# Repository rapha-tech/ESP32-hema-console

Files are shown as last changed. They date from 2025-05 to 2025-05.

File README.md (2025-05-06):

# ESP32 hema console
 New PCB for the small console from hema to use an ESP32

## <https://github.com/ducalex/retro-go>
The esp32 uses Retro-go to emulate games

## Side by side comparison with the original one
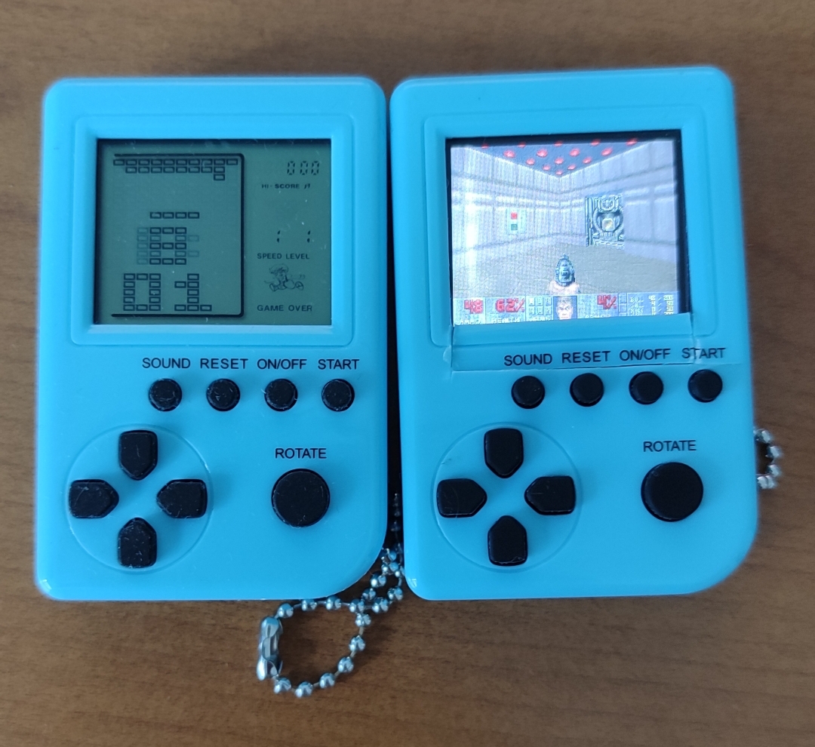
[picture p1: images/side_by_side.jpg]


## Some pictures of the PCB
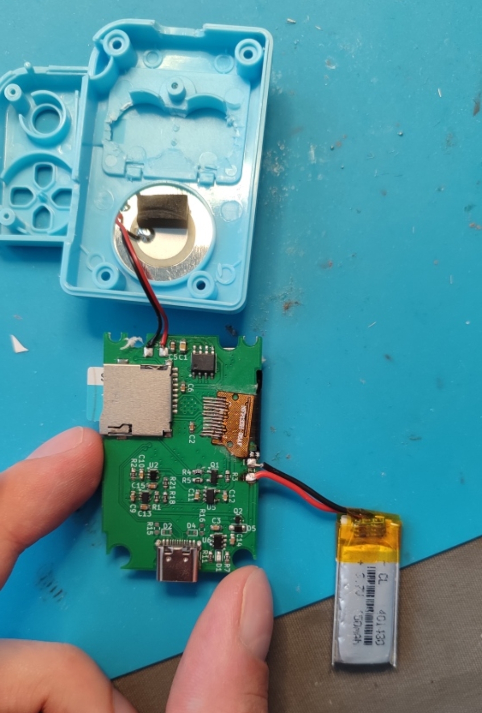
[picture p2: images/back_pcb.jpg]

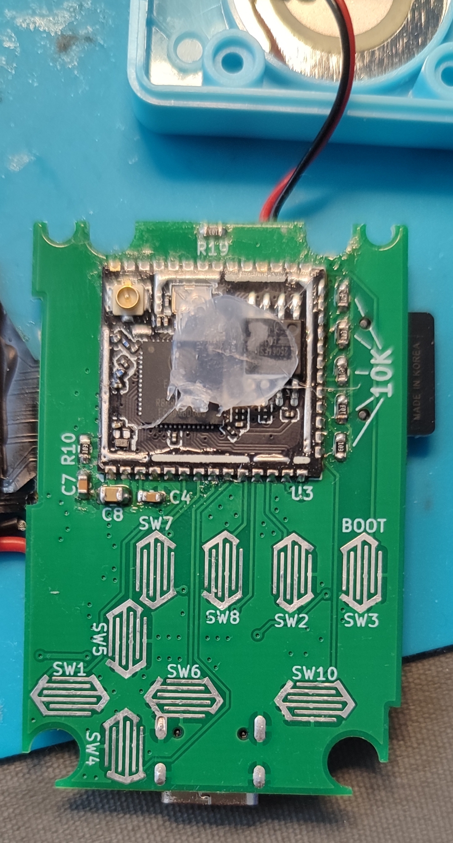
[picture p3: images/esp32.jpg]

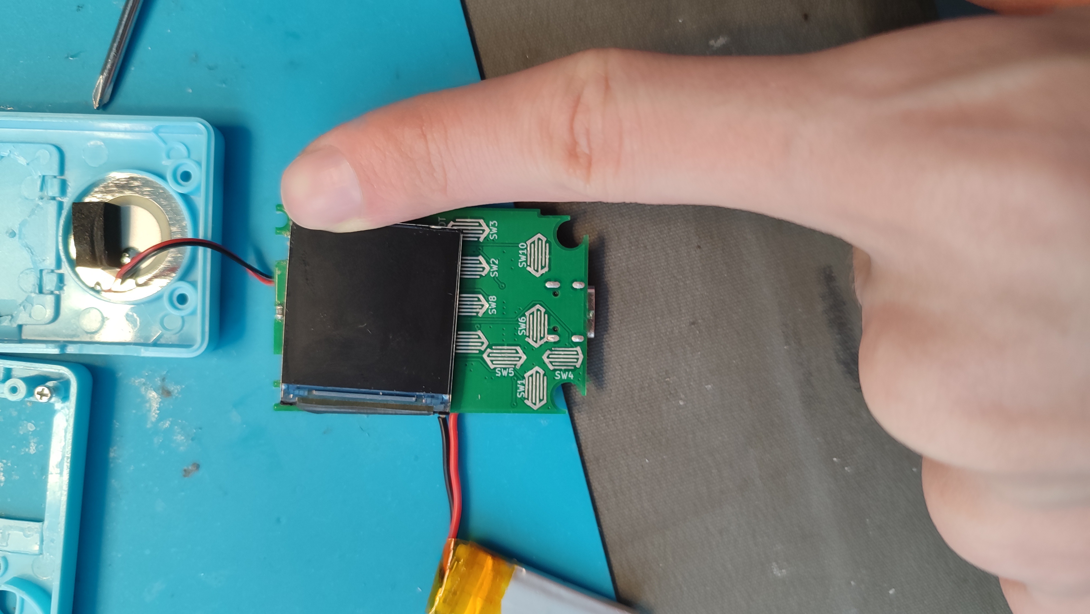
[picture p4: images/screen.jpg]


Known problems :
- The buttons doesn't make great contact compared to the original PCB

Components :
- ESP32 module without PCB antenna
- 1.54 inches IPS 240*240px
- about 3*30*30mm battery or 4*15*30mm

Note : it is almost the same schematic as my Retro-Ruler
## <https://github.com/rapha-tech/Retro-Ruler>

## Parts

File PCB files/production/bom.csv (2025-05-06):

Designator | Footprint | Quantity | Value | LCSC Part #
B1 | BAT | 1 | battery_3.7v
C1, C8 | 0805 | 2 | 10uF
C10, C11, C12, C4, C9 | 0603 | 5 | 1uF
C13, C15, C2, C5, C6, C7 | 0603 | 6 | 100nF
C14, C3 | 0603 | 2 | 2.2uF
D1 | 0603 | 1 | RLED
D2, D4 | D_SOD-523 | 2 | LESD5D5.0CT1G
D5 | D_SOD-323_HandSoldering | 1 | BAT760
DS1 | ST7789-320x240 | 1 | ST7789
J1 | USB_C_Receptacle_GCT_USB4105-xx-A_16P_TopMnt_Horizontal | 1 | USB_C_Receptacle_USB2.0_14P
J2 | micro_sd | 1 | Micro_SD_Card
Q1 | SOT-23 | 1 | NPN_S9013
Q2 | SOT-723 | 1 | CJ3139K
R1, R10, R13, R14, R18, R19, R2, R21, R5, R6, R8, R9 | 0603 | 12 | 10K
R11 | 0603 | 1 | 4K7
R15, R16 | 0603 | 2 | 5K1
R3 | 0603 | 1 | 10R
R4, R7 | 0603 | 2 | 1K
S1 | BAT | 1 | Speaker
SW1 | Membrane Button Hema Console | 1 | LEFT
SW10 | Membrane Button Hema Console | 1 | A
SW2 | Membrane Button Hema Console | 1 | START
SW3 | Membrane Button Hema Console | 1 | B
SW4 | Membrane Button Hema Console | 1 | DOWN
SW5 | Membrane Button Hema Console | 1 | UP
SW6 | Membrane Button Hema Console | 1 | RIGHT
SW7 | Membrane Button Hema Console | 1 | ON/OFF
SW8 | Membrane Button Hema Console | 1 | MENU
U2 | SOT-353_SC-70-5 | 1 | 74LVC1G17
U3 | ESP32-S3-WROOM-1 | 1 | ESP32-S3-WROOM-1
U4 | HSOP-8-1EP_3.9x4.9mm_P1.27mm_EP2.3x2.3mm | 1 | NS4168
U5 | SOT-23-5 | 1 | AP2112K-3.3
U6 | SOT-23-5 | 1 | TP4054
U7 | SOT-353_SC-70-5 | 1 | SN74LVC1G80DCKR

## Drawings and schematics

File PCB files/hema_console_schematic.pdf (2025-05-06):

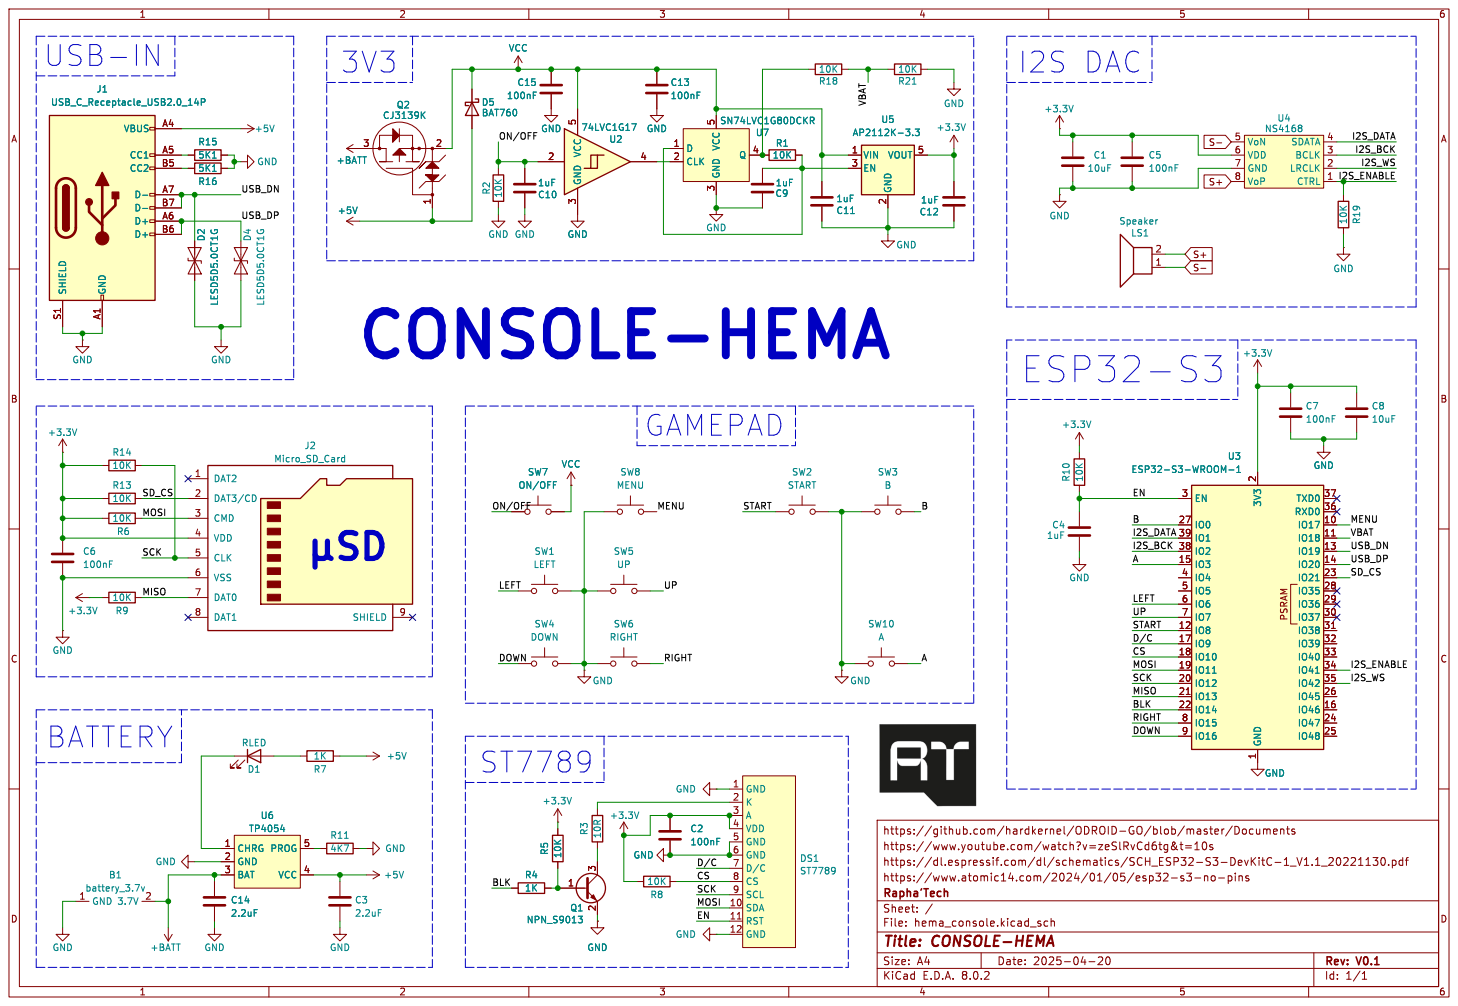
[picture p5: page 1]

https://www.youtube.com/watch?v=zeSlRvCd6tg&t=10s
https://dl.espressif.com/dl/schematics/SCH_ESP32-S3-DevKitC-1_V1.1_20221130.pdf
https://www.atomic14.com/2024/01/05/esp32-s3-no-pins
File: hema_console.kicad_sch Sheet: / Rapha'Tech

Id: 1/1 Title: CONSOLE-HEMA

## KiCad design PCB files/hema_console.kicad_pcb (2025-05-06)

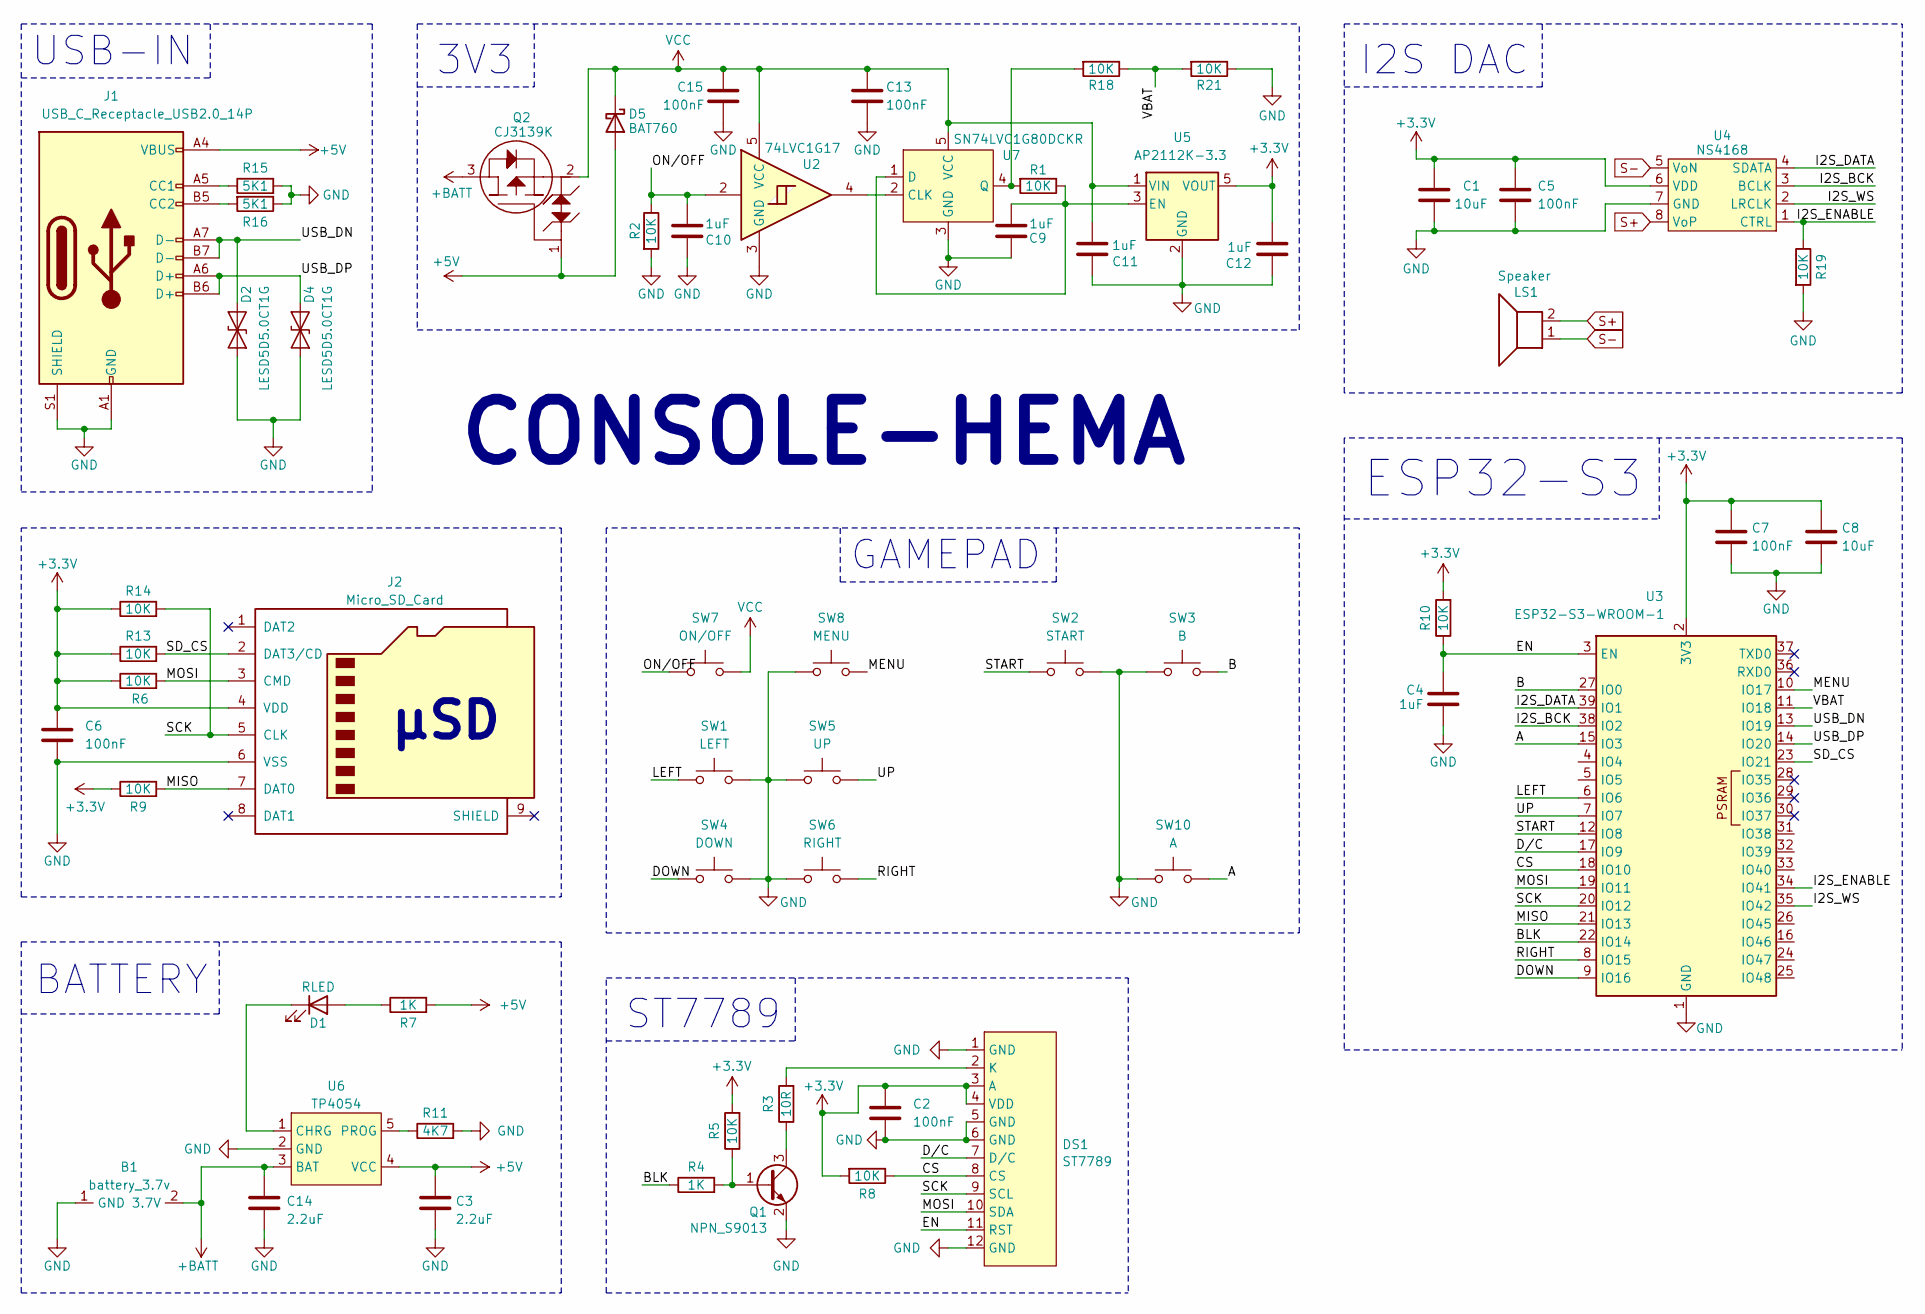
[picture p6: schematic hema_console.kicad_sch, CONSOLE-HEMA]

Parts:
B1: battery_3.7v; BAT
C1, C8: 10uF; C_0805_2012Metric
C2, C5, C6, C7, C13, C15: 100nF; C_0603_1608Metric
C3, C14: 2.2uF; C_0603_1608Metric
C4, C9, C10, C11, C12: 1uF; C_0603_1608Metric
D1: RLED; LED_0603_1608Metric
D2, D4: LESD5D5.0CT1G; D_SOD-523
D5: BAT760; D_SOD-323_HandSoldering
DS1: ST7789; ST7789-320x240
J1: USB_C_Receptacle_USB2.0_14P; USB_C_Receptacle_GCT_USB4105-xx-A_16P_TopMnt_Horizontal
J2: Micro_SD_Card; micro_sd
LS1: Speaker; BAT
Q1: NPN_S9013; SOT-23
Q2: CJ3139K; SOT-723
R1, R2, R5, R6, R8, R9, R10, R13, R14, R18, R19, R21: 10K; R_0603_1608Metric
R3: 10R; R_0603_1608Metric
R4, R7: 1K; R_0603_1608Metric
R11: 4K7; R_0603_1608Metric
R15, R16: 5K1; R_0603_1608Metric
SW1: LEFT; Membrane Button Hema Console
SW2: START; Membrane Button Hema Console
SW3: B; Membrane Button Hema Console
SW4: DOWN; Membrane Button Hema Console
SW5: UP; Membrane Button Hema Console
SW6: RIGHT; Membrane Button Hema Console
SW7: ON/OFF; Membrane Button Hema Console
SW8: MENU; Membrane Button Hema Console
SW10: A; Membrane Button Hema Console
U2: 74LVC1G17; SOT-353_SC-70-5
U3: ESP32-S3-WROOM-1
U4: NS4168; HSOP-8-1EP_3.9x4.9mm_P1.27mm_EP2.3x2.3mm
U5: AP2112K-3.3; SOT-23-5
U6: TP4054; SOT-23-5
U7: SN74LVC1G80DCKR; SOT-353_SC-70-5

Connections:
+3.3V: C1.2, C2.1, C5.2, C6.1, C7.1, C8.2, C12.1, DS1.3 (A), DS1.4 (VDD), J2.4 (VDD), R5.2, R6.1, R8.2, R9.1, R10.2, R13.1, R14.1, U3.2 (3V3), U4.6 (VDD), U5.5 (VOUT)
+5V: C3.1, D5.2 (A), J1.A4 (VBUS), J1.A9 (VBUS), J1.B4 (VBUS), J1.B9 (VBUS), Q2.1, R7.2, U6.4 (VCC)
+BATT: B1.2 (3.7V), C14.1, Q2.3, U6.3 (BAT)
/A: SW10.2, U3.15 (IO3)
/B: SW3.2, U3.27 (IO0)
/BLK: R4.1, U3.22 (IO14)
/CS: DS1.8 (CS), R8.1, U3.18 (IO10)
/DOWN: SW4.1, U3.9 (IO16)
/D/C: DS1.7 (D/C), U3.17 (IO9)
/EN: C4.2, DS1.11 (RST), R10.1, U3.3 (EN)
/I2S_BCK: U3.38 (IO2), U4.3 (BCLK)
/I2S_DATA: U3.39 (IO1), U4.4 (SDATA)
/I2S_ENABLE: R19.1, U3.34 (IO41), U4.1 (CTRL)
/I2S_WS: U3.35 (IO42), U4.2 (LRCLK)
/LEFT: SW1.1, U3.6 (IO6)
/MENU: SW8.2, U3.10 (IO17)
/MISO: J2.7 (DAT0), R9.2, U3.21 (IO13)
/MOSI: DS1.10 (SDA), J2.3 (CMD), R6.2, U3.19 (IO11)
/ON/OFF: C10.2, R2.1, SW7.1, U2.2
/RIGHT: SW6.2, U3.8 (IO15)
/SCK: DS1.9 (SCL), J2.5 (CLK), R14.2, U3.20 (IO12)
/SD_CS: J2.2 (DAT3/CD), R13.2, U3.23 (IO21)
/START: SW2.1, U3.12 (IO8)
/UP: SW5.2, U3.7 (IO7)
/USB_DN: D2.2 (A2), J1.A7 (D-), J1.B7 (D-), U3.13 (IO19)
/USB_DP: D4.2 (A2), J1.A6 (D+), J1.B6 (D+), U3.14 (IO20)
/VBAT: R18.1, R21.2, U3.11 (IO18)
GND: B1.1 (GND), C1.1, C2.2, C3.2, C4.1, C5.1, C6.2, C7.2, C8.1, C9.1, C10.1, C11.1, C12.2, C13.2, C14.2, C15.2, D2.1 (A1), D4.1 (A1), DS1.1 (GND), DS1.5 (GND), DS1.6 (GND), DS1.12 (GND), J1.A1 (GND), J1.A12 (GND), J1.B1 (GND), J1.B12 (GND), J1.S1 (SHIELD), J2.6 (VSS), Q1.2 (E), R2.2, R11.2, R15.2, R16.1, R19.2, R21.1, SW1.2, SW2.2, SW3.1, SW4.2, SW5.1, SW6.1, SW8.1, SW10.1, U2.3 (GND), U3.1 (GND), U3.40 (GND), U3.41 (GND), U4.7 (GND), U5.2 (GND), U6.2 (GND), U7.3 (GND)
unnamed: D1.2 (A), R7.1
unnamed: D1.1 (K), U6.1 (CHRG)
unnamed: DS1.2 (K), R3.2
unnamed: J1.A5 (CC1), R15.1
unnamed: J1.B5 (CC2), R16.2
unnamed: Q1.1 (B), R4.2, R5.1
unnamed: Q1.3 (C), R3.1
unnamed: C9.2, R1.1, U5.3 (EN), U7.1 (D)
unnamed: R11.1, U6.5 (PROG)
unnamed: U2.4, U7.2 (CLK)
unnamed: R1.2, R18.2, U7.4 (Q)
S+: LS1.2, U4.8 (VoP); also elsewhere on the board
S-: LS1.1, U4.5 (VoN); also elsewhere on the board
VCC: C11.2, C13.1, C15.1, D5.1 (K), Q2.2, SW7.2, U2.5 (VCC), U5.1 (VIN), U7.5 (VCC)

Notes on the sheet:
BATTERY
I2S DAC
μSD
3V3
GAMEPAD
CONSOLE-HEMA
ESP32-S3
USB-IN
ST7789

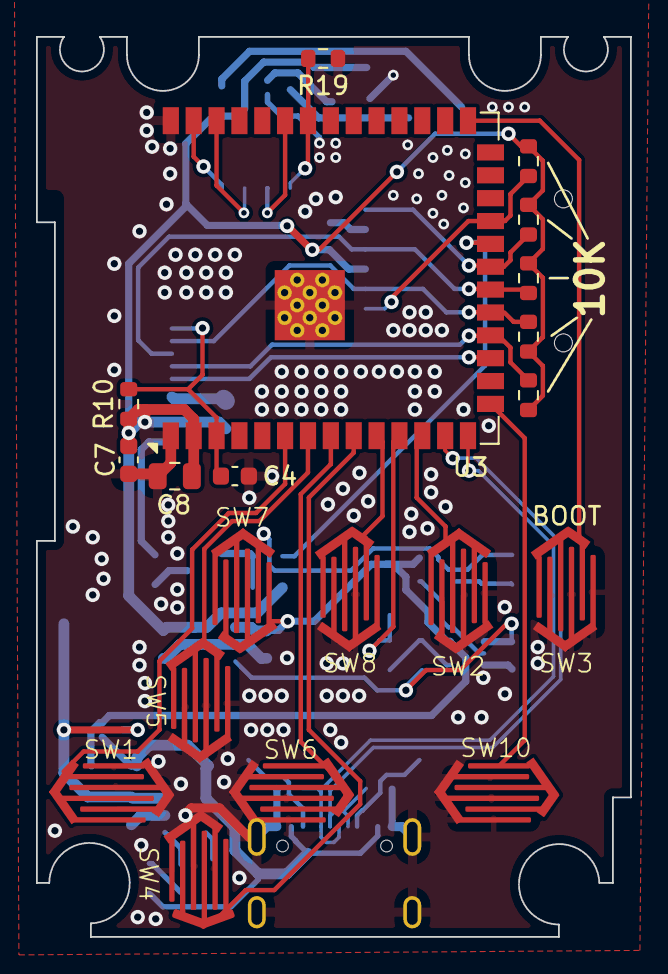
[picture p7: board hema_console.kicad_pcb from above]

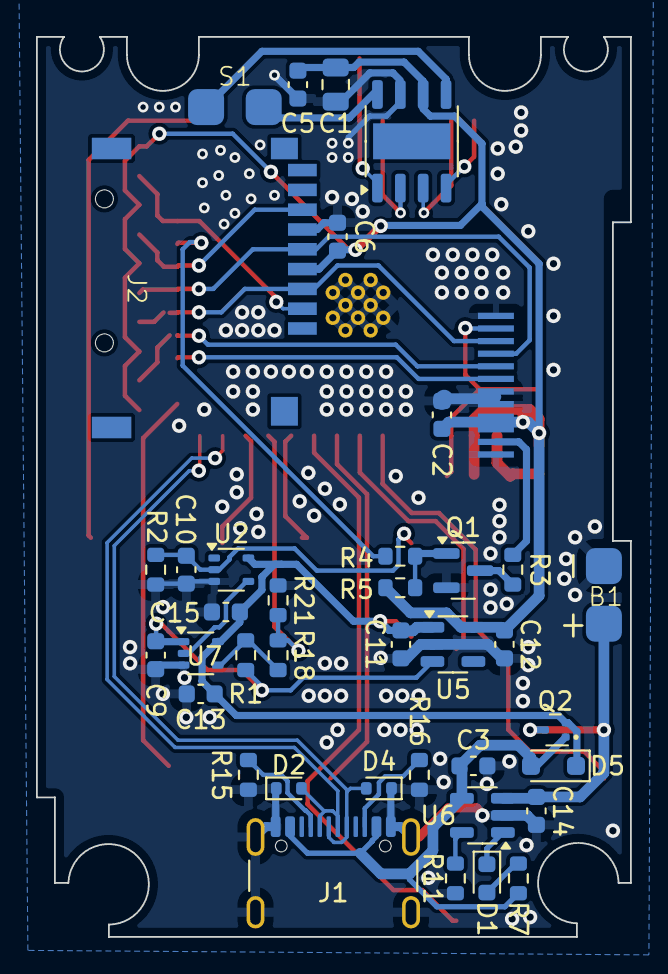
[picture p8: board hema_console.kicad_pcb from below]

Board: 2 copper layers, 33.0 x 50.0 mm, 59 parts (39 on the bottom side), 42 nets.

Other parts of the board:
S1: Speaker; BAT

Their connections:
S+: S1.2; also elsewhere on the board
S-: S1.1; also elsewhere on the board
